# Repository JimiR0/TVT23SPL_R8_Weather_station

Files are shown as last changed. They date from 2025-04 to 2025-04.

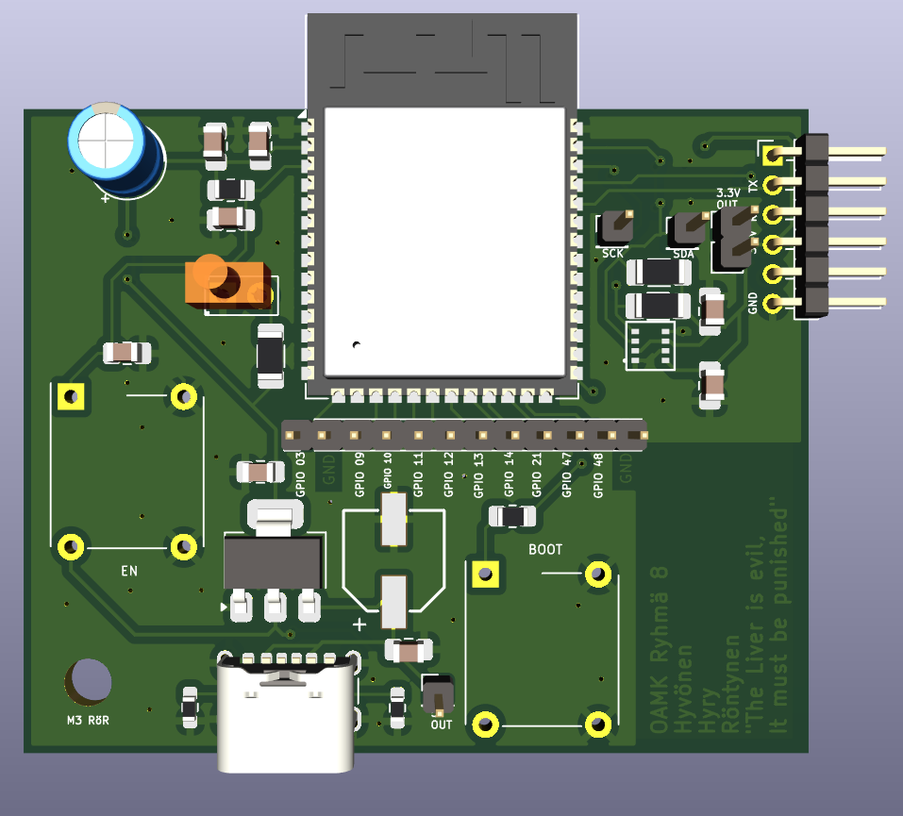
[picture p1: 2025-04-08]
PICS/PCB_3D_FRONT.PNG

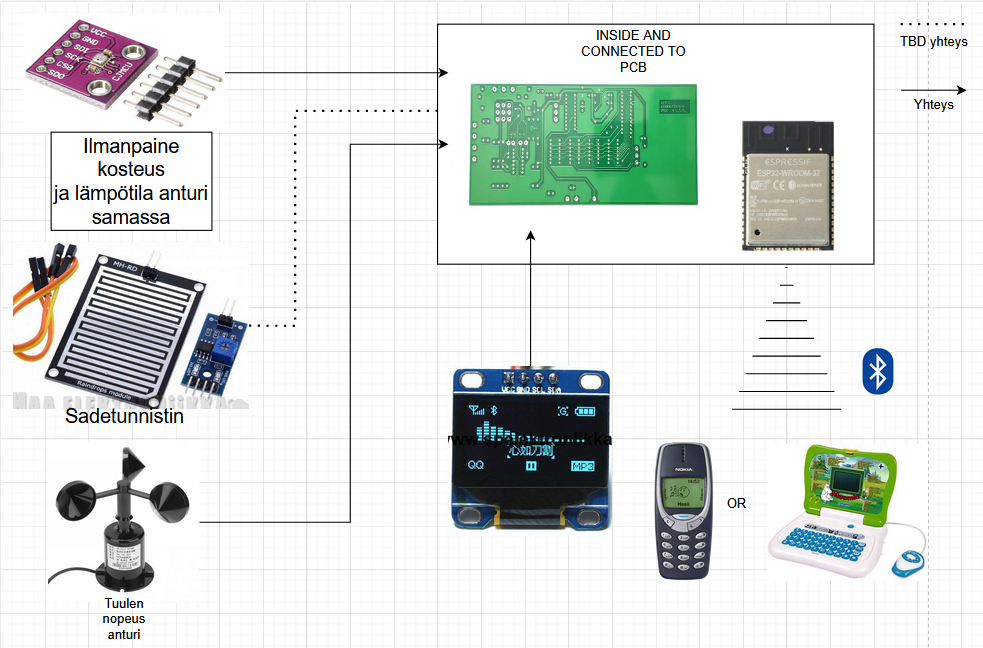
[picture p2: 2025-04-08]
PICS/PROJEKTI_KUVA.PNG

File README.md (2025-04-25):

# TVT23SPL_R8_Weather_station
# Electronics Application Project

The electronics application project is part of the second-year studies in the Bachelor’s Degree in Information and Communication Technology. It serves as the final project for the second year and has been designed to challenge students and their skills by requiring them to build a device of their own choosing, which includes an analog interface and a microcontroller.
________________________________________
## Project Architecture

________________________________________
## Project Goal
The main goals of the project were:

•	To design and build a functional PCB

•	To build a functional and portable weather station around the PCB, equipped with sensors for wind speed, humidity, air pressure, and temperature

•	To transmit the sensor values via Bluetooth to a computer, and via wires to an OLED display

•	To integrate the weather station into a hat
________________________________________
## Practical Experience

•	Designing and building a PCB

•	Soldering small components onto the PCB

•	Device-oriented design

•	Deeper understanding of Bluetooth Low Energy
________________________________________
## Project Implementation in Phases

Phase 1: Coming up with the project idea and planning its implementation

Phase 2: Ordering the components and starting to write code

Phase 3: Designing and ordering the PCB

Phase 4: Soldering the components onto the PCB and testing functionality

Phase 5: Finalizing the code to working condition

Phase 6: Assembling the project and testing it for presentation
________________________________________
## Devices and Technology Used

Here you can find the components, applications and devices that helped with the project:

•	KiCad

•	Arduino IDE

•	ESP32 Wroom 1

•	OLED display

•	BME280 sensor

•	TCST1103 Photo Interrupter

(KUVA 1. ESP32 Devkit)

Näyttö(KUVA 2. OLED-näyttö)

BME280_sensor(KUVA 3. BME280 sensori)

Optohaarukka(KUVA 4. TCST1103 Optohaarukka)

________________________________________
## Learning Experiences and Challenges

During the project, we gained extensive experience in device-oriented design and programming. Especially the circuit design and implementation provided both learning opportunities and challenges. The most difficult part turned out to be getting the entire system to work together.
Challenges included:
•	Designing the PCB to be just right for our use
•	Getting the optical fork (opto-interrupter) to work with the ESP32
•	Displaying data correctly on the OLED display
•	Fitting all project components into a hat
________________________________________
## Hardware Links

ESP32 Devkit
________________________________________
## Summary

The electronics application project was a challenging experience in terms of skills and learning, and it was the most demanding part of the academic year. However, it was extremely educational and valuable for our future careers. The goal of our project was to build a functional, head-worn weather station that displays wind speed, humidity, and temperature in real time to the user. We believe we succeeded in the project, as we met the goals we had set for ourselves, and the project was a success.

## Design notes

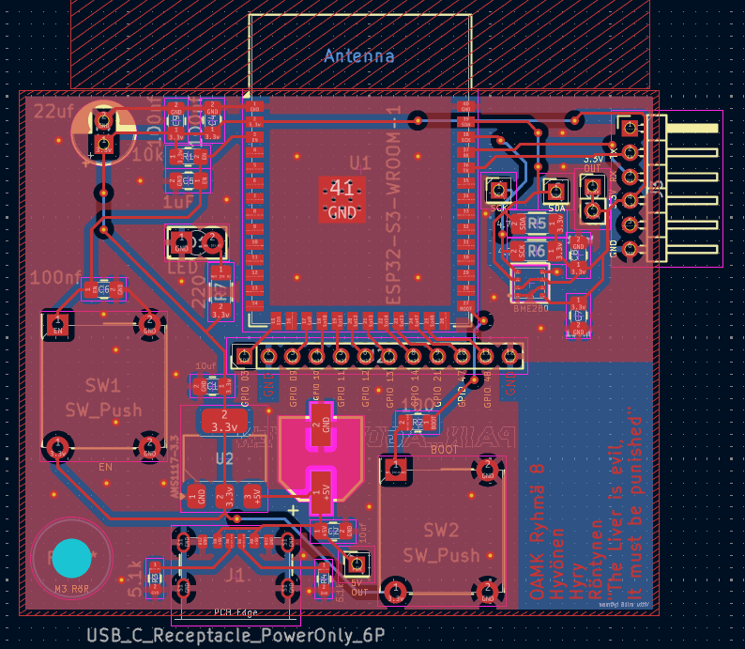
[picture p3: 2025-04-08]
PICS/PCB_kuva.PNG

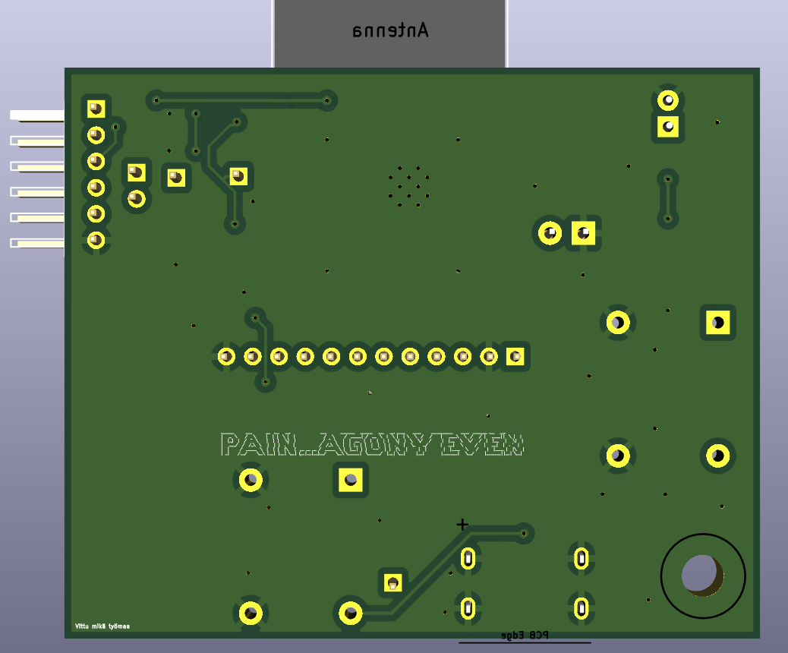
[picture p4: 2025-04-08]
PICS/PCB_3D_BACK.PNG

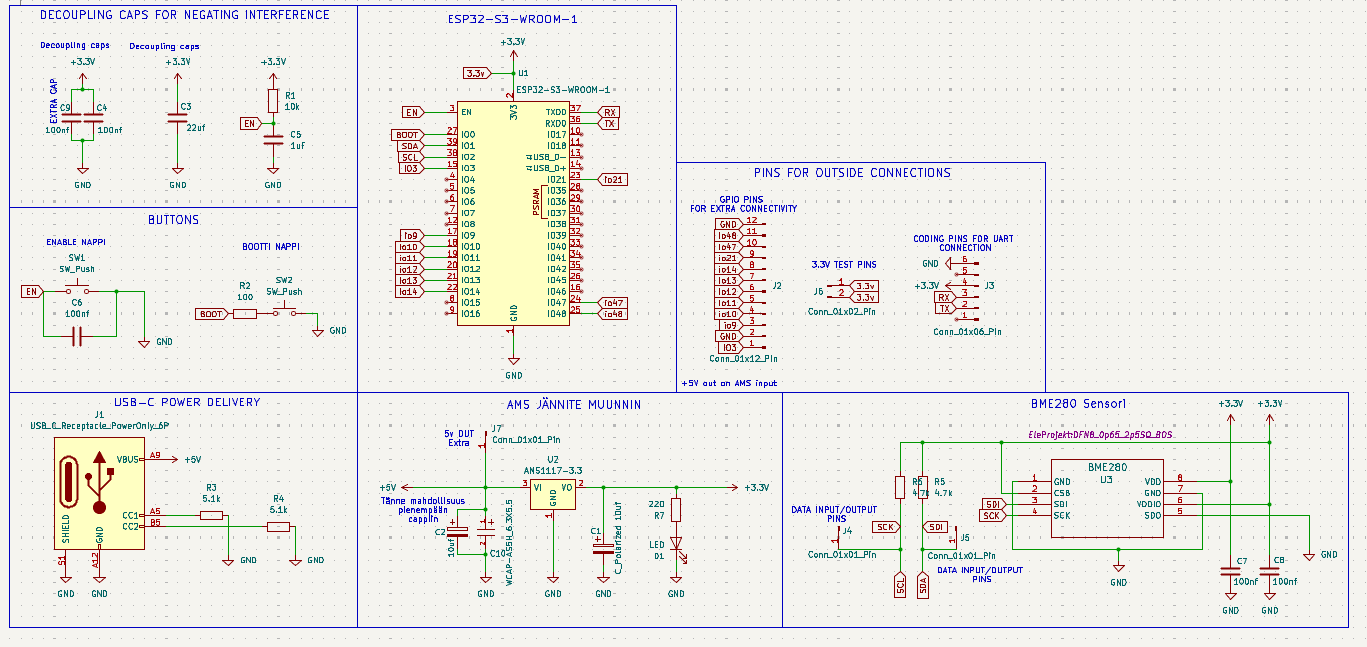
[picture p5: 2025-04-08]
PICS/PCB_SCHEMA_ALL.PNG

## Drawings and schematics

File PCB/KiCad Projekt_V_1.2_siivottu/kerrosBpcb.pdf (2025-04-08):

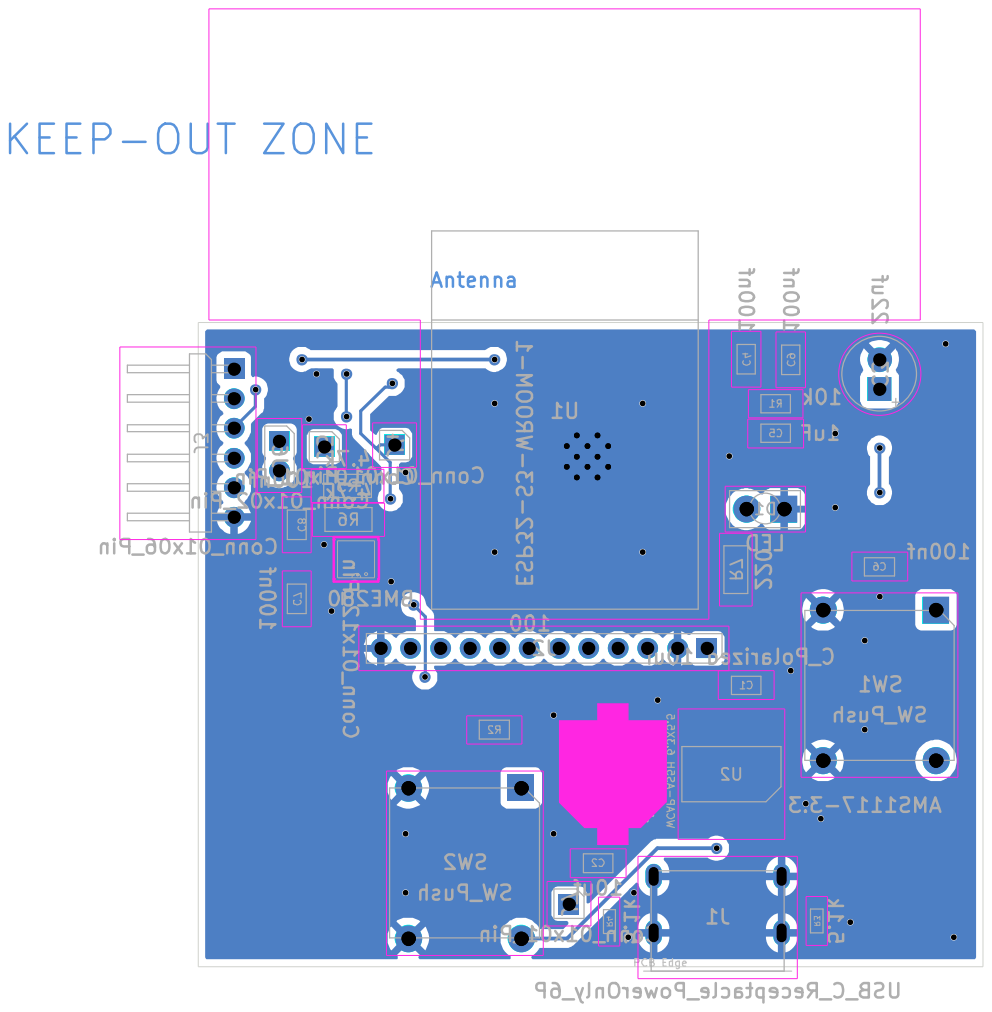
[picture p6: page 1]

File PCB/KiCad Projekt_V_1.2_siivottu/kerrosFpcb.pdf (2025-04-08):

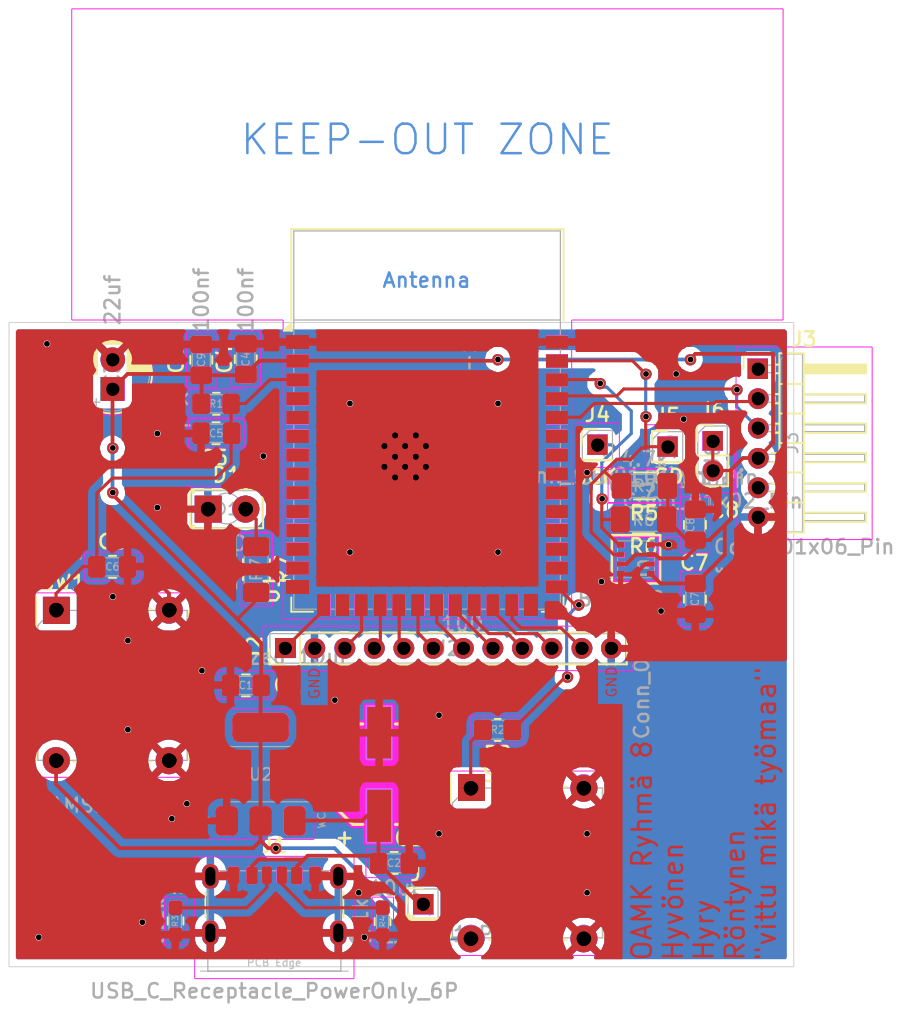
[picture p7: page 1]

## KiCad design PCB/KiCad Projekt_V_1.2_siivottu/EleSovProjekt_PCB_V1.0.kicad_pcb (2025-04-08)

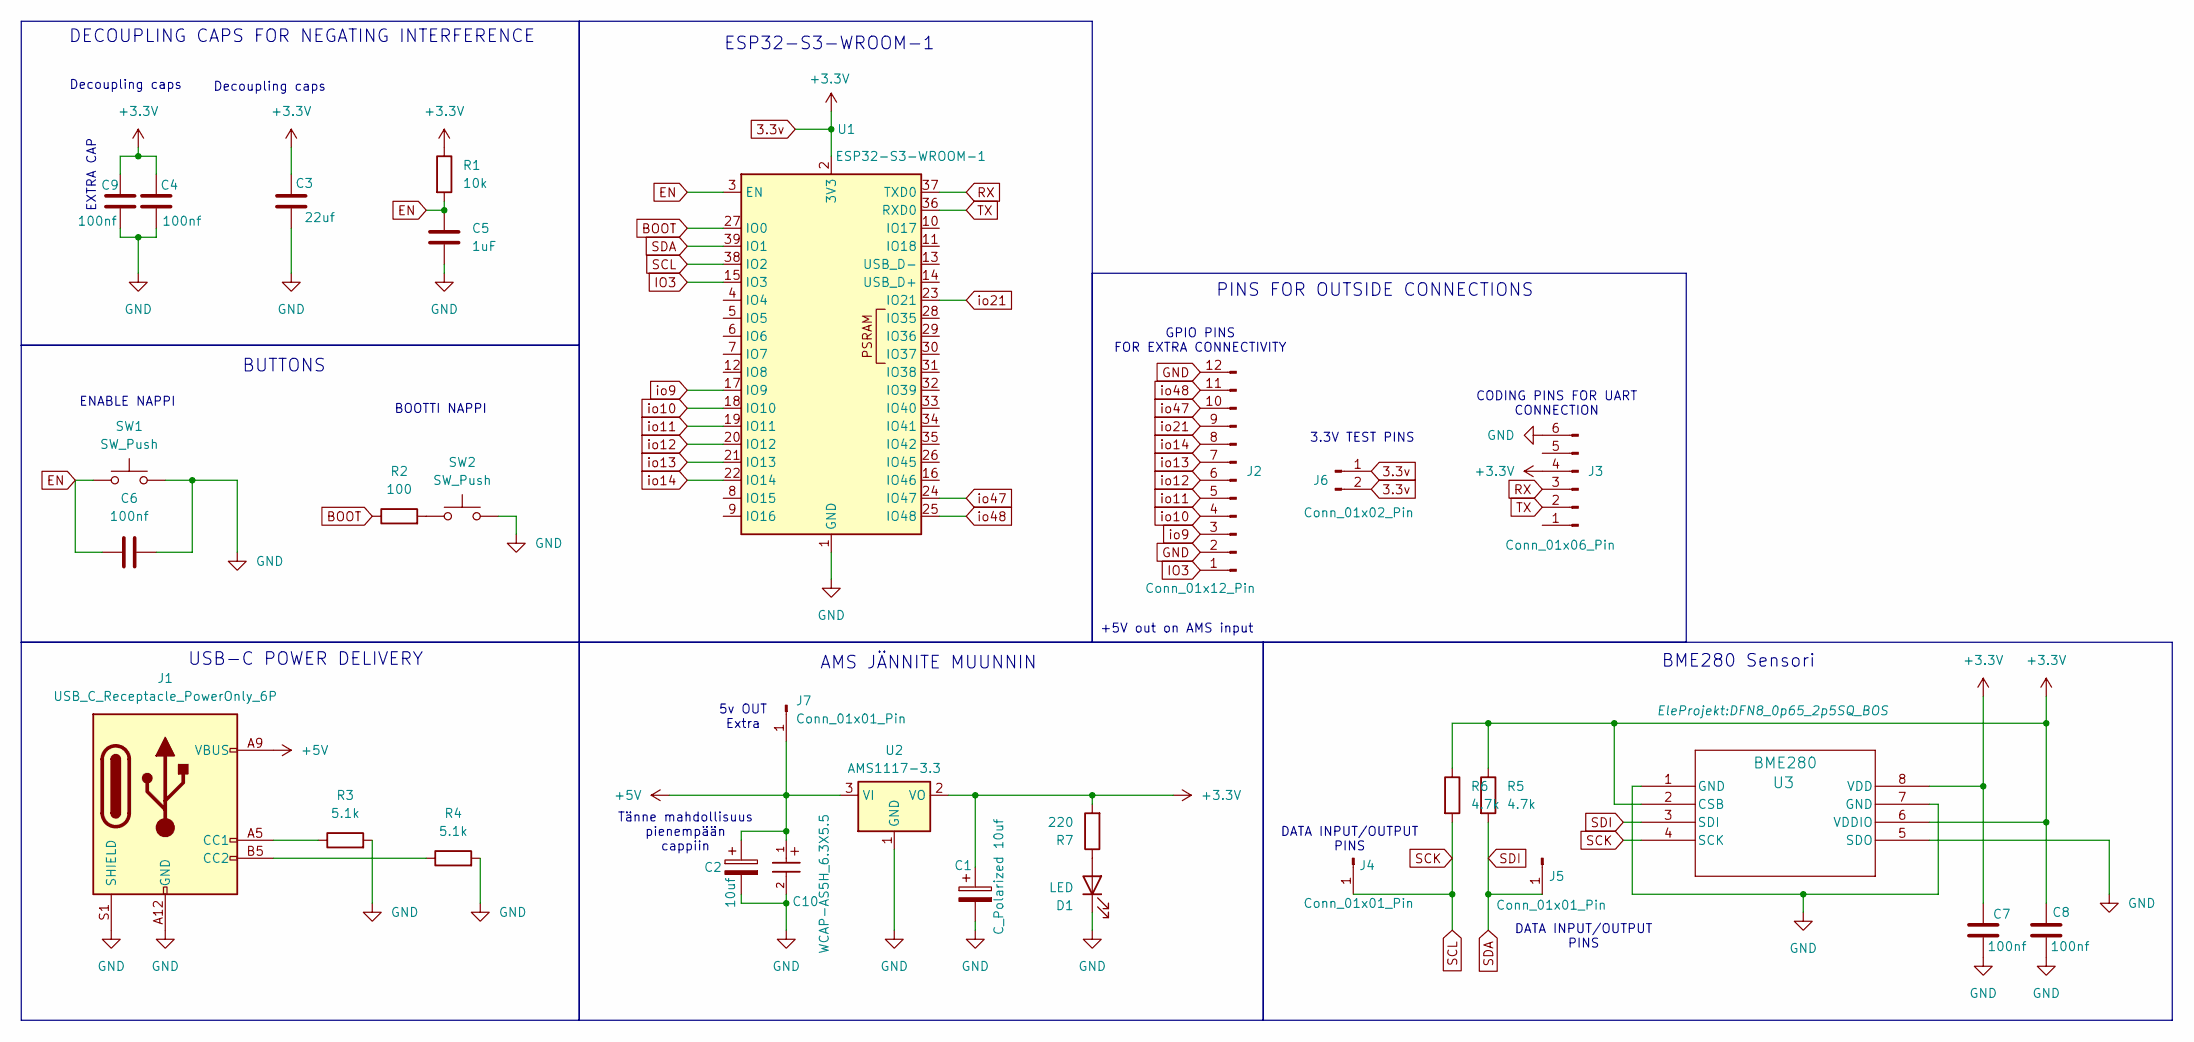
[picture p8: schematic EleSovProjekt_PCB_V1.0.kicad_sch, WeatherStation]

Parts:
C1: C_Polarized 10uf; C_0805_2012Metric_Pad1.18x1.45mm_HandSolder
C2: 10uf; C_0805_2012Metric_Pad1.18x1.45mm_HandSolder
C3: 22uf; CP_Radial_D5.0mm_P2.00mm
C4, C6, C7, C8, C9: 100nf; C_0805_2012Metric_Pad1.18x1.45mm_HandSolder
C5: 1uF; C_0805_2012Metric_Pad1.18x1.45mm_HandSolder
C10: WCAP-AS5H_6.3X5.5; WCAP-AS5H_6.3X5.5_DXL_
D1: LED; LED_D2.0mm_W4.8mm_H2.5mm_FlatTop
J1: USB_C_Receptacle_PowerOnly_6P; USB_C_Receptacle_GCT_USB4125-xx-x-0190_6P_TopMnt_Horizontal
J2: Conn_01x12_Pin; PinHeader_1x12_P2.54mm_Vertical
J3: Conn_01x06_Pin; PinHeader_1x06_P2.54mm_Horizontal
J4, J5, J7: Conn_01x01_Pin; PinHeader_1x01_P2.54mm_Vertical
J6: Conn_01x02_Pin; PinHeader_1x02_P2.54mm_Vertical
R1: 10k; R_0805_2012Metric_Pad1.20x1.40mm_HandSolder
R2: 100; R_0805_2012Metric_Pad1.20x1.40mm_HandSolder
R3, R4: 5.1k; R_0603_1608Metric_Pad0.98x0.95mm_HandSolder
R5, R6: 4.7k; R_1206_3216Metric_Pad1.30x1.75mm_HandSolder
R7: 220; R_1206_3216Metric_Pad1.30x1.75mm_HandSolder
SW1, SW2: SW_Push; SW_MEC_5GTH9
U1: ESP32-S3-WROOM-1
U2: AMS1117-3.3; SOT-223-3_TabPin2
U3: BME280; DFN8_0p65_2p5SQ_BOS

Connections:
3.3v: C1.1, C3.1, C4.1, C7.1, C8.1, C9.1, J3.4, J6.1, J6.2, R1.1, R5.1, R6.1, R7.2, SW1.1, SW2.1, U1.2 (3V3), U2.2 (VO), U3.2 (CSB), U3.6 (VDDIO), U3.8 (VDD)
+5V: C2.1, C10.1, J1.A9 (VBUS), J1.B9 (VBUS), J7.1, U2.3 (VI)
BOOT: R2.1, U1.27 (IO0)
EN: C5.1, C6.1, R1.2, SW1.1, U1.3 (EN)
GND: C1.2, C2.2, C3.2, C4.2, C5.2, C6.2, C7.2, C8.2, C9.2, C10.2, D1.1 (K), J1.A12 (GND), J1.B12 (GND), J1.S1 (SHIELD), J2.2, J2.12, J3.6, R3.2, R4.2, SW1.2, SW2.2, U1.1 (GND), U1.40 (GND), U1.41 (GND), U2.1 (GND), U3.1 (GND), U3.5 (SDO), U3.7 (GND)
IO3: J2.1, U1.15 (IO3)
unnamed: D1.2 (A), R7.1
unnamed: J1.A5 (CC1), R3.1
unnamed: J1.B5 (CC2), R4.1
unnamed: R2.2, SW2.1
RX: J3.3, U1.37 (TXD0)
SCK: J4.1, R6.2, U1.38 (IO2), U3.4 (SCK)
SDA: J5.1, R5.2, U1.39 (IO1), U3.3 (SDI)
TX: J3.2, U1.36 (RXD0)
io9: J2.3, U1.17 (IO9)
io10: J2.4, U1.18 (IO10)
io11: J2.5, U1.19 (IO11)
io12: J2.6, U1.20 (IO12)
io13: J2.7, U1.21 (IO13)
io14: J2.8, U1.22 (IO14)
io21: J2.9, U1.23 (IO21)
io47: J2.10, U1.24 (IO47)
io48: J2.11, U1.25 (IO48)

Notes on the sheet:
BME280 Sensori
Tänne mahdollisuus pienempään cappiin
DATA INPUT/OUTPUT PINS
EXTRA CAP
Decoupling caps
5v OUT Extra
GPIO PINS FOR EXTRA CONNECTIVITY
USB-C POWER DELIVERY
3.3V TEST PINS
DECOUPLING CAPS FOR NEGATING INTERFERENCE
ENABLE NAPPI
+5V out on AMS input
PINS FOR OUTSIDE CONNECTIONS
BUTTONS
ESP32-S3-WROOM-1
BOOTTI NAPPI
AMS JÄNNITE MUUNNIN
CODING PINS FOR UART CONNECTION

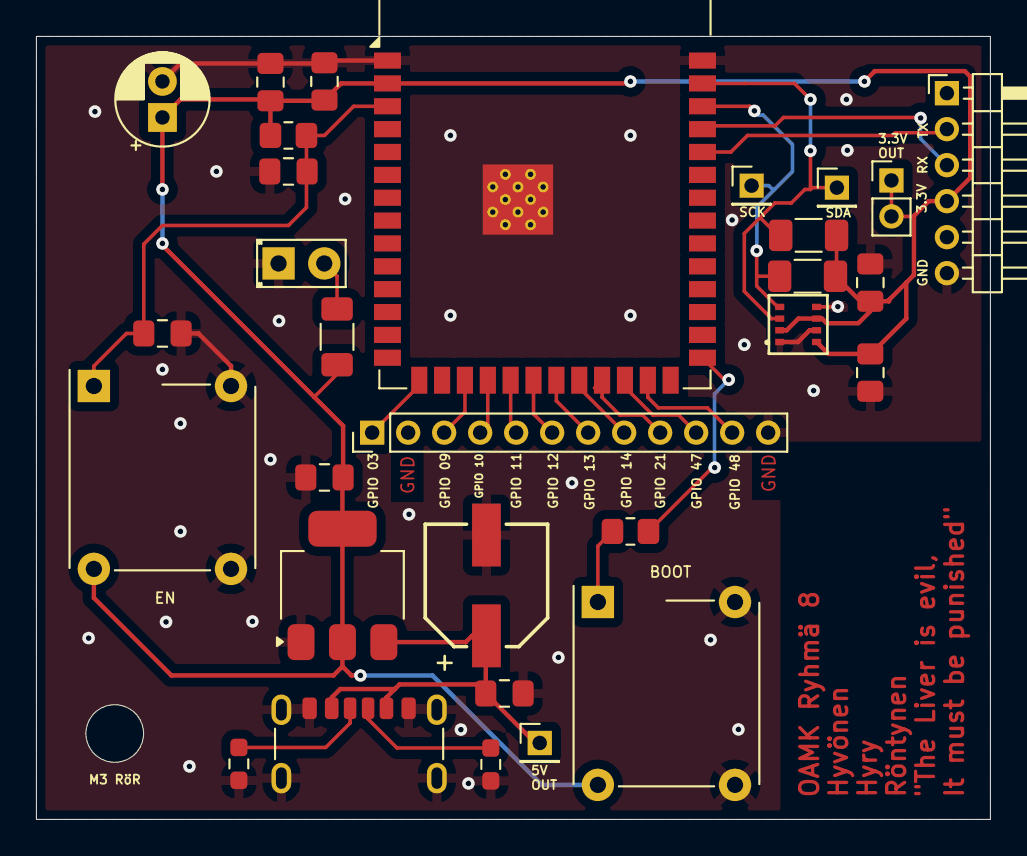
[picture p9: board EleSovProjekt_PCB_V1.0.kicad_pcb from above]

Board: 2 copper layers, 53.0 x 43.5 mm, 30 parts (0 on the bottom side), 23 nets.

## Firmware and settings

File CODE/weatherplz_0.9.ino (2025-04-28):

#include <Wire.h>
#include <Adafruit_GFX.h>
#include <Adafruit_SSD1306.h>
#include <Adafruit_Sensor.h>
#include <Adafruit_BME280.h>

#define SCREEN_WIDTH 128 // OLED display width, in pixels
#define SCREEN_HEIGHT 64 // OLED display height, in pixels
#define WIRE Wire

int pin = 11;
int val;                                                              //calibration value
long last=0;                                                          //used in timing - holds thelast milis count
int stat1=LOW;                                                         //used in calibration
int stat2;                                                            //used in calibration
int counter=0;                                                        //used to count light/dark iterations

int stat3=0;                                                          //counterit  
int stat4=0;

int sens=75;                                                          //calibration value
                 
int slots=16; 

int milisecs=500;   

Adafruit_SSD1306 display(SCREEN_WIDTH, SCREEN_HEIGHT, &Wire, -1);
Adafruit_BME280 bme; // Create BME280 object

void setup() {
  Serial.begin(115200);
WIRE.begin(1,2);

  if(!display.begin(SSD1306_SWITCHCAPVCC, 0x3C)) {
    Serial.println(F("SSD1306 allocation failed"));
    for(;;);
  }
  display.display();
  delay(100);
  display.clearDisplay();
  display.display();
  display.setTextSize(1.9);
  display.setTextColor(WHITE);
  bool status = bme.begin(0x76);
  if (!status) {
    Serial.println("Could not find a valid BME280 sensor, check wiring!");
    while (1);
  }

  delay(2000);
  display.clearDisplay();
  display.setTextColor(WHITE);
}

void loop() {

 val=analogRead(pin);                                                  //light or dark?
  if(val<sens)                                                        //within calibartion value?
    stat1=LOW;                                                         //set var to LOW
   else                                                               //if not
    stat1=HIGH;                                                        //set var HIGH
   digitalWrite(13,stat1);                                             //LED on or off
                          
 
   if(stat2!=stat1){                                                   //if there has been a change
                     
     counter++;                                                       //increment counter
     stat2=stat1;                                                      //remember last value
   }
   if(millis()-last>=milisecs){                                       //has time passed?
     double rps=((double)counter/slots)/2.0*1000.0/milisecs;          //do math
     double rpm=((double)counter/slots)/2.0*60000.0/(milisecs);   
     double kmh= 0.0543 * rpm - 9.716;
     double ms= kmh / 3.6;
     /*display.clearDisplay();                                          //clear display & buffer
     display.setTextSize(1);                                          //prepare to show stuff
     display.setTextColor(WHITE);
     display.setCursor(0,0);
     //display.print((counter/2.0));
     //display.println("  RPS ");
     //display.print(rps);
     display.print("RPM ");                                           //print out the units we are using to buffer
     display.println(rpm);                                            //print out the value returned by the maths
     display.display(); */                                              //show me the buffer!
                                                 //remember this moment


  display.setCursor(0,0);
  display.clearDisplay();
  
  display.setCursor(0,0);
  //Serial.print("Temperature = "); Serial.print(bme.readTemperature());
  display.print("Temperature: "); display.print(bme.readTemperature()); display.print("C");

  display.setCursor(0,15);
  //Serial.print("Pressure = "); Serial.print(bme.readPressure() / 100.0F);
  display.print("Pressure: "); display.print(bme.readPressure() / 100.0F); display.print("hPa");

  display.setCursor(0,30);
  //Serial.print("Humidity = "); Serial.print(bme.readHumidity());
  display.print("Humidity: "); display.print(bme.readHumidity()); display.print("%");

  display.setCursor(0,45);  
 // display.print("RPM ");                                           //print out the units we are using to buffer
  //display.println(rpm); 

  display.print("m/s ");                                           
  display.println(ms);

       
  counter=0;                                                       //reset counter
  last=millis();  

  Serial.println();
  display.display();
  //delay(1000);
  //Serial.println(stat3);
  //stat3++;

  //stat3 = 0;
    //RPM();
  }
  }
/*
void RPM(){
    for (int i = 0; i < 100; i++) {
  Serial.println("RPM");
  val=analogRead(pin);                                                  //light or dark?
  if(val<sens)                                                        //within calibartion value?
    stat1=LOW;                                                         //set var to LOW
   else                                                               //if not
    stat1=HIGH;                                                        //set var HIGH
   digitalWrite(13,stat1);                                             //LED on or off
                          
 
   if(stat2!=stat1){                                                   //if there has been a change
                     
     counter++;                                                       //increment counter
     stat2=stat1;                                                      //remember last value
   }
   if(millis()-last>=milisecs){                                       //has time passed?
     double rps=((double)counter/slots)/2.0*1000.0/milisecs;          //do maths
     double rpm=((double)counter/slots)/2.0*60000.0/(milisecs);       //do more maths
     display.clearDisplay();                                          //clear display & buffer
     display.setTextSize(1);                                          //prepare to show stuff
     display.setTextColor(WHITE);
     display.setCursor(0,0);
     //display.print((counter/2.0));
     //display.println("  RPS ");
     //display.print(rps);
     display.print("RPM ");                                           //print out the units we are using to buffer
     display.println(rpm);                                            //print out the value returned by the maths
     display.display();                                               //show me the buffer!
     
     counter=0;                                                       //reset counter
     last=millis();                                                   //remember this moment

}}}
*/

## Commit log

2025-04-08 PCB,Code
    first iterations of code and older and final version of PCB
    [EleSovProjekt_PCB_V1.0.kicad_pcb, EleSovProjekt_PCB_V1.0.kicad_sch]
2025-04-08 Pictures
    Pictures of PCB,Schema and overall connectivity
